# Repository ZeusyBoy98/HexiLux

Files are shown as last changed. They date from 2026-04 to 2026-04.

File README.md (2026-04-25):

# HexiLux
Made for Hack Club Fallout.

## Zine
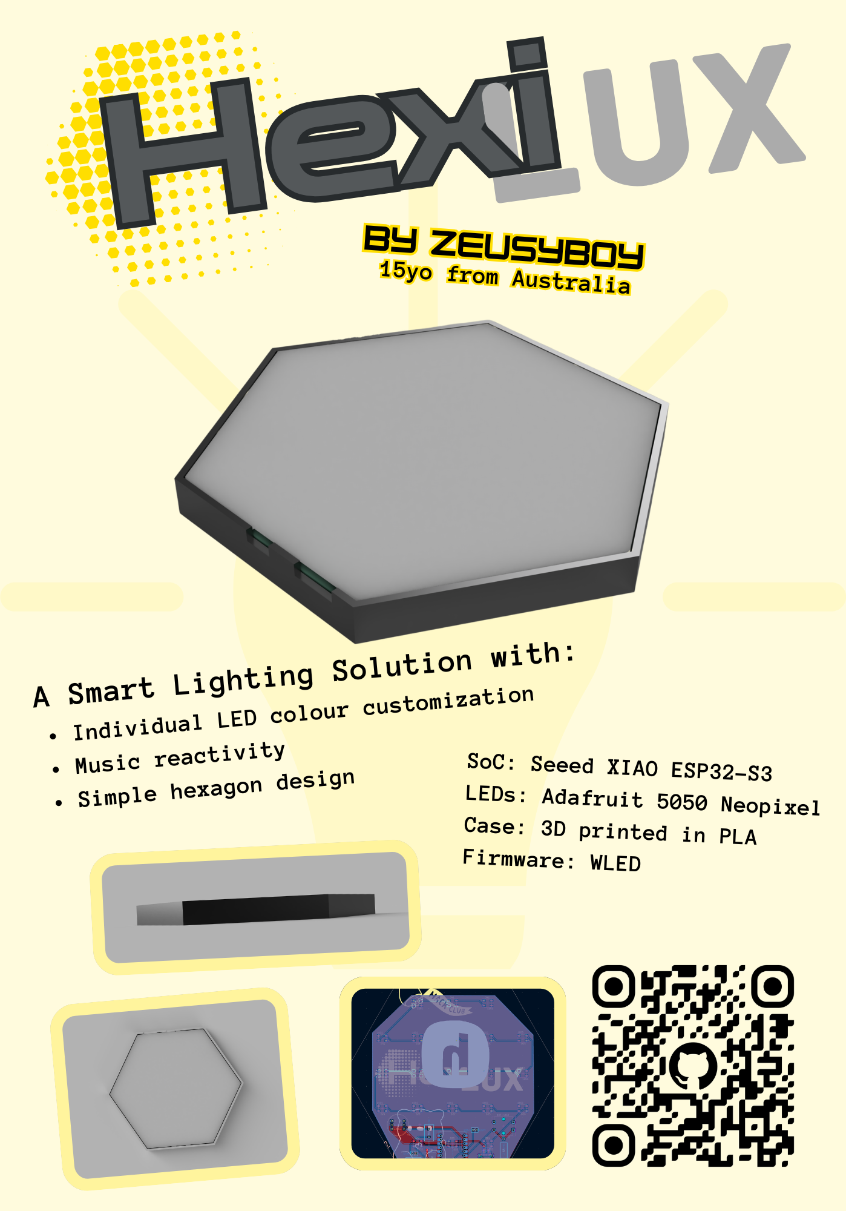
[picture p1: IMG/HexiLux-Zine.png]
Zine


## What does it do?
A custom open-source smart lighting solution, using tiling hexagonal panels. Featuring music sync and home assistant compatibility. 

## Why/Motivation?
Because I enjoy DJing and music reactive lights to go behind my setup would be really cool and elevate my experience.

## How?
In order to make this project for yourself, you'll need to purchase/3D print the items in the bill of materials below.

| Quantity | Item | URL | Unit Price ($USD) | Total Price ($USD)  |
| --- | --- | --- | --- | --- |
| 1 | Microphone | [Zaitronics](https://zaitronics.com.au/products/inmp441-i2s-mems-omnidirectional-microphone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) | 5.57 | 5.57 |
| 3 | Neopixel (10 pack) | [DigiKey](https://www.digikey.com.au/en/products/detail/adafruit-industries-llc/1655/5154679) | 4.50 | 13.50 |
| 1 | Button | [DigiKey](https://www.digikey.com.au/en/products/detail/omron-electronics-inc-emc-div/B3F-4050/95200) | 0.52 | 0.52 |
| 1 | Board<br> | [DigiKey](https://www.digikey.com.au/en/products/detail/seeed-technology-co-ltd/113991114/19285530) | 7.49 | 7.49 |
| 4 | 100nF Capacitor | [DigiKey](https://www.digikey.com.au/en/products/detail/vishay-beyschlag-draloric-bc-components/K104K15X7RF5TL2/286538) | 0.28 | 1.12 |
| 1 | 330 Resistor | [DigiKey](https://www.digikey.com.au/en/products/detail/yageo/FMP200JR-52-330R/2058682) | 0.19 | 0.19 |
| 1 | 10k Resistor | [DigiKey](https://www.digikey.com.au/en/products/detail/yageo/FMP200JR-52-10K/2058646) | 0.19 | 0.19 |
| 2 | 5.1k Resistor | [DigiKey](https://www.digikey.com.au/en/products/detail/yageo/RC0603FR-075K1L/727268) | 0.10 | 0.20 |
| 1 | 47uF Capacitor | [DigiKey](https://www.digikey.com.au/en/products/detail/tdk/FK20X5R0J476MN000/2815373) | 0.86 | 0.86 |
| 1 | 100uF Capacitor | [DigiKey](https://www.digikey.com.au/en/products/detail/murata-electronics/GRM31CD80J107MEA8L/13904781) | 0.44 | 0.44 |
| 1 | Level Shifter | [DigiKey](https://www.digikey.com.au/en/products/detail/texas-instruments/SN74AHCT1G125DBVR/376028) | 0.14 | 0.14 |
| 1 | USBC | [DigiKey](https://www.digikey.com.au/en/products/detail/amphenol-cs-fci/10155435-00011LF/11602060) | 0.85 | 0.85 |
| | Case | 3D print files in /CAD | (3D printing: 1.17) | (3D printing: 1.17) |
| PCB | | | | 29.24 |
| Shipping | | | | 3.70+20+9.52=33.22  |
| Total | | | | 93.53 |

### Build Guide:

#### 1. Preparation
Before starting, make sure you have:
<ul>
<li>All components from the BOM
<li>A soldering iron + solder
<li>Tweezers (there are lots of small components)
<li>Flux (helpful)
<li>A 3D printer (or get the printed parts from someone else)
<li>A USB-C cable
<li>A USB-C power adapter
</ul>

#### 2. Soldering
Take your pcb and begin soldering components to it<br>
Wiring schematic:
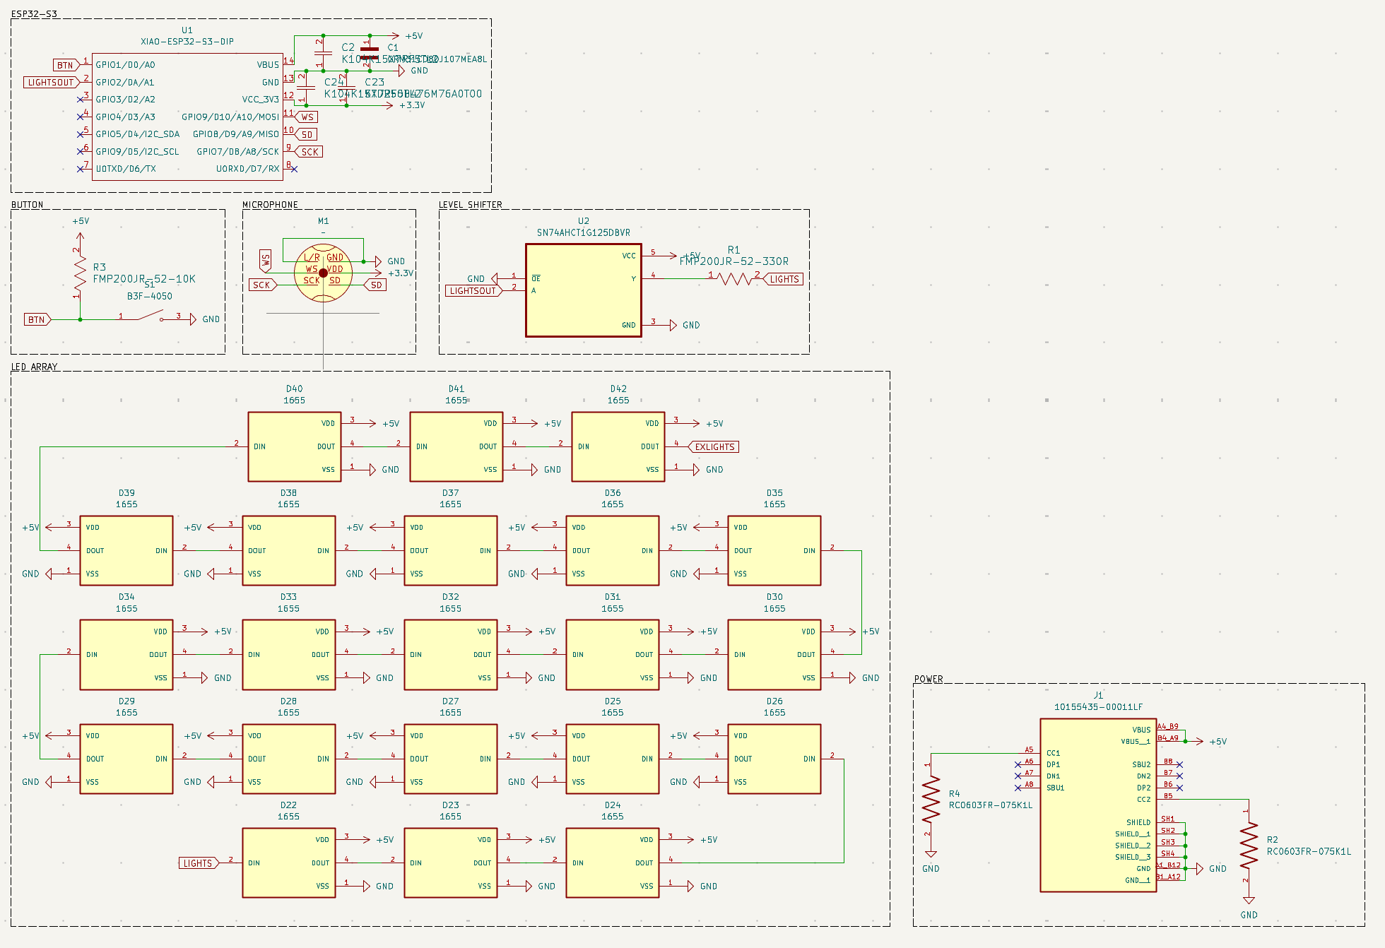
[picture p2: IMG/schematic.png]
schematic

Recommended order:
<ul>
<li>SMD Components (resistors/capacitors, neopixels, logic converters)
<li>Microcontroller (Seeed XIAO ESP32-S3)
<li>Through-hole components (resistors/capacitors, buttons, microphone)
</ul>

#### 3. Case
<ul>
<li>3D print the case bottom and top.
<li>Place the PCB into the case bottom
<li>Snap on the case top
</ul>

#### 4. Firmware
<ul>
<li>Plug the middle USB-C port (ESP32-S3) into a computer
<li>Go to https://install.wled.me/
<li>Install the WLED firmware to the board
<li>Unplug
<li>Plug a power adapter into the off-centre USB-C port
<li>Follow the instructions here to start using: https://kno.wled.ge/basics/getting-started/
</ul>

Enjoy your HexiLux panel!

## Renders
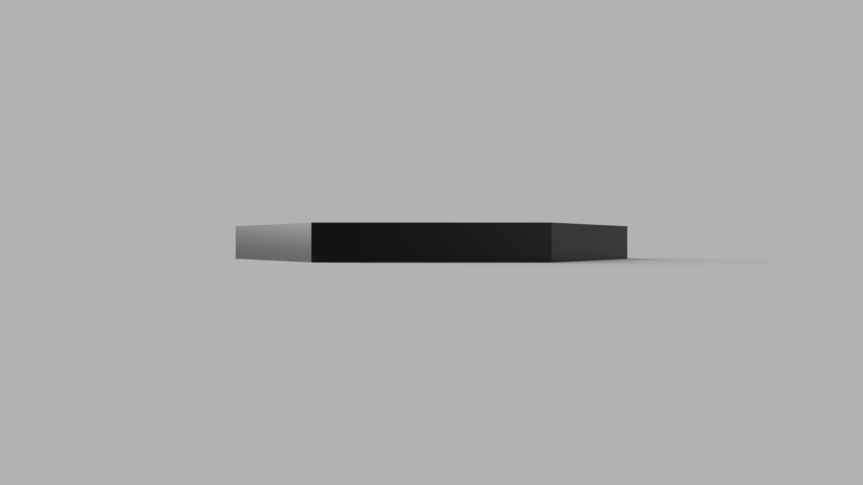
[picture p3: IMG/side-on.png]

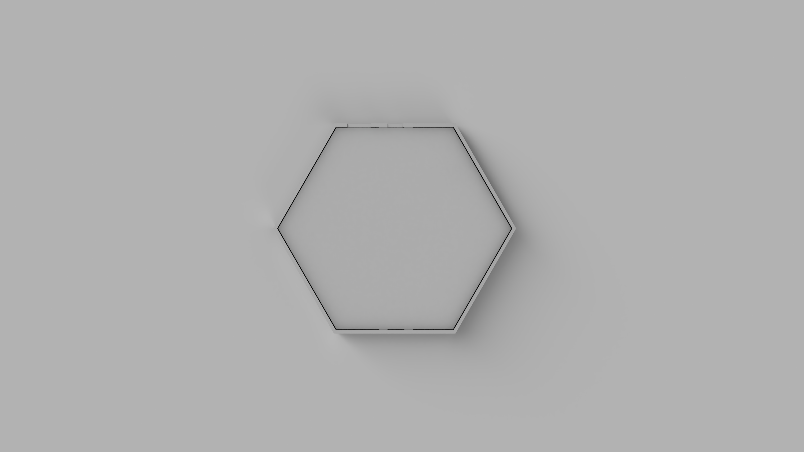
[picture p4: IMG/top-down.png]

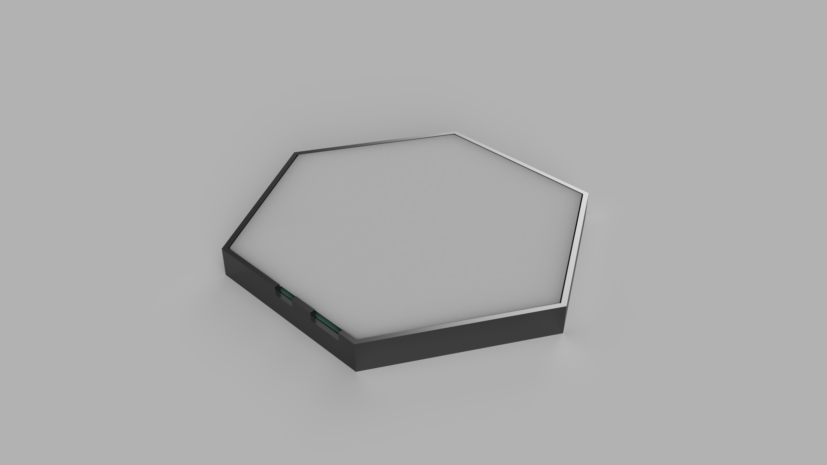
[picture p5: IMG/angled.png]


## Designing
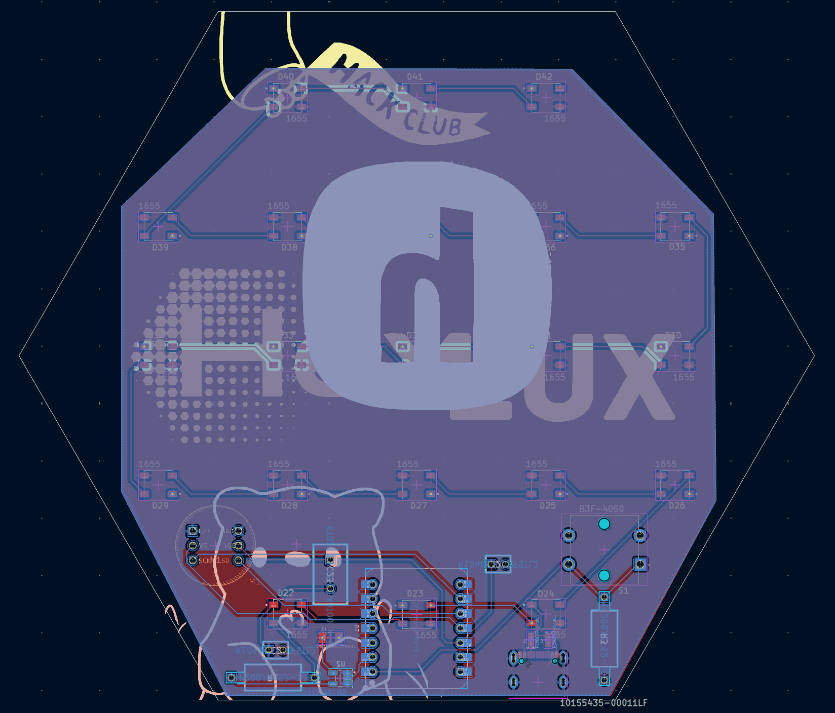
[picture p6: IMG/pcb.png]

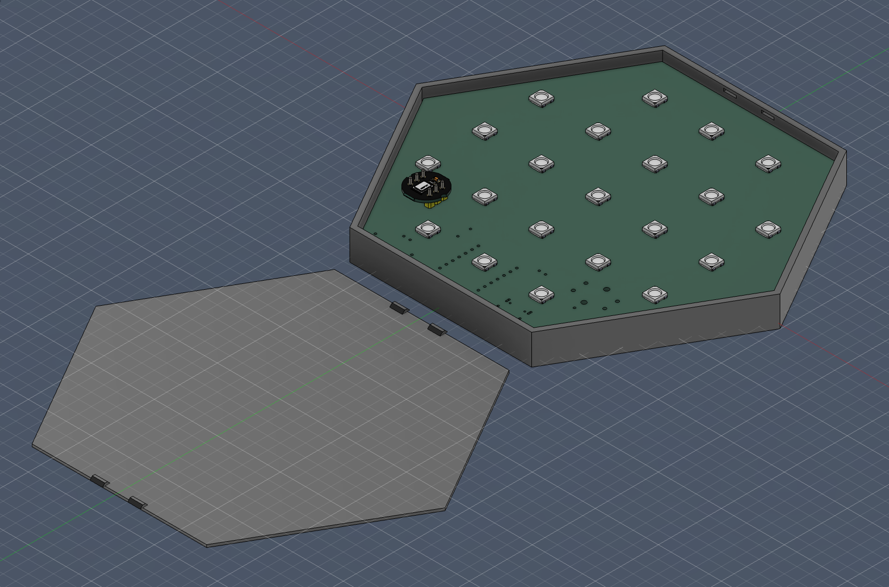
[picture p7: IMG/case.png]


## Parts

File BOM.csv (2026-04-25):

Quantity | Item | URL | Unit Price ($USD) | Total Price ($USD)
1 | Microphone | https://zaitronics.com.au/products/inmp441-i2s-mems-omnidirectional-microphone?variant=51395922100516 | 5.57 | 5.57
3 | Neopixel (10 pack) | https://www.digikey.com.au/en/products/detail/adafruit-industries-llc/1655/5154679 | 4.50 | 13.50
1 | Button | https://www.digikey.com.au/en/products/detail/omron-electronics-inc-emc-div/B3F-4050/95200 | 0.52 | 0.52
1 | Board<br> | https://www.digikey.com.au/en/products/detail/seeed-technology-co-ltd/113991114/19285530 | 7.49 | 7.49
4 | 100nF Capacitor | https://www.digikey.com.au/en/products/detail/vishay-beyschlag-draloric-bc-components/K104K15X7RF5TL2/286538 | 0.28 | 1.12
1 | 330 Resistor | https://www.digikey.com.au/en/products/detail/yageo/FMP200JR-52-330R/2058682 | 0.19 | 0.19
1 | 10k Resistor | https://www.digikey.com.au/en/products/detail/yageo/FMP200JR-52-10K/2058646 | 0.19 | 0.19
2 | 5.1k Resistor | https://www.digikey.com.au/en/products/detail/yageo/RC0603FR-075K1L/727268 | 0.10 | 0.20
1 | 47uF Capacitor | https://www.digikey.com.au/en/products/detail/tdk/FK20X5R0J476MN000/2815373 | 0.86 | 0.86
1 | 100uF Capacitor | https://www.digikey.com.au/en/products/detail/murata-electronics/GRM31CD80J107MEA8L/13904781 | 0.44 | 0.44
1 | Level Shifter | https://www.digikey.com.au/en/products/detail/texas-instruments/SN74AHCT1G125DBVR/376028 | 0.14 | 0.14
1 | USBC | https://www.digikey.com.au/en/products/detail/amphenol-cs-fci/10155435-00011LF/11602060 | 0.85 | 0.85
 | Case | 3D print files in /CAD | (3D printing: 1.17) | (3D printing: 1.17)
PCB |  |  |  | 29.24
Shipping |  |  |  | 3.70+20+9.52=33.22
Total |  |  |  | 93.53

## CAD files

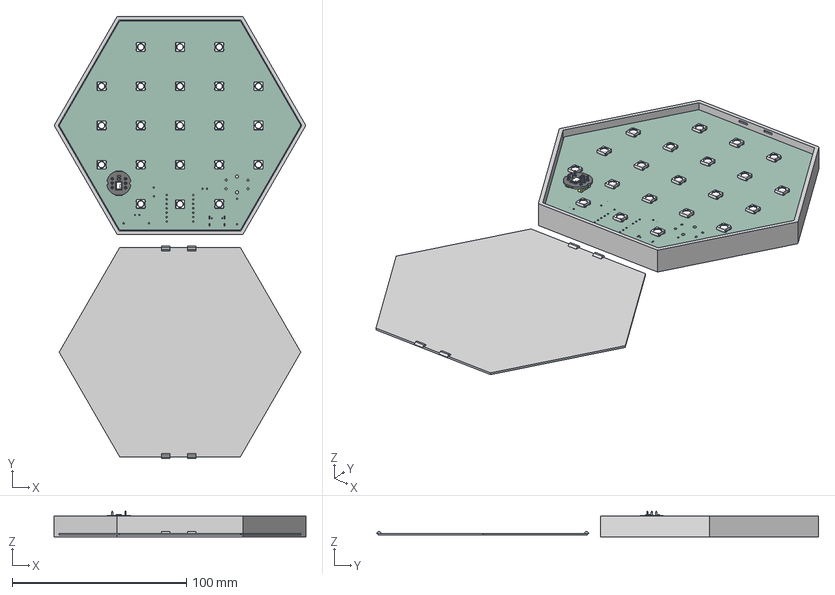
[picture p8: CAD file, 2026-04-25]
CAD/HexiLux-Full.stp
144.4 x 253.5 x 14.7 mm

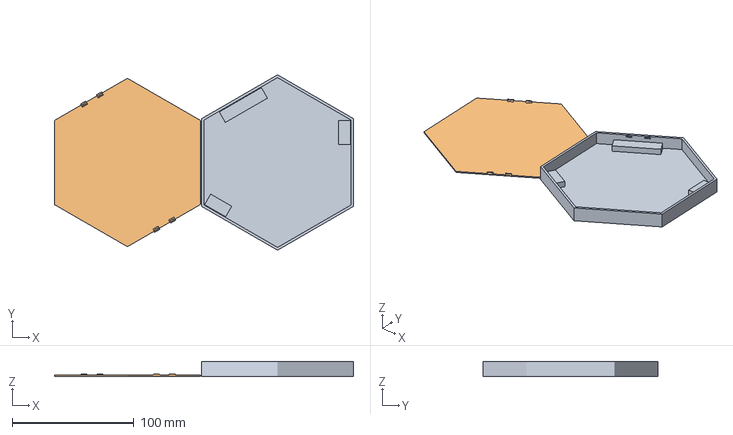
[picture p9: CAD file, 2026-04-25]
CAD/HexiLux-Print.3mf
246.0 x 144.3 x 12.0 mm
HexiLux-Bottom.stp
HexiLux-Top.stp

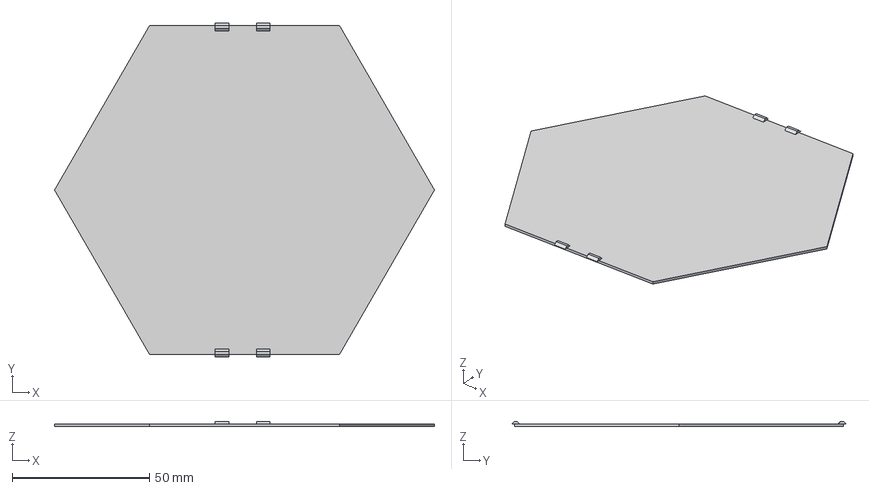
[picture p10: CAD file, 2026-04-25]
CAD/Parts/HexiLux-Top.stp
138.6 x 122.0 x 2.00 mm

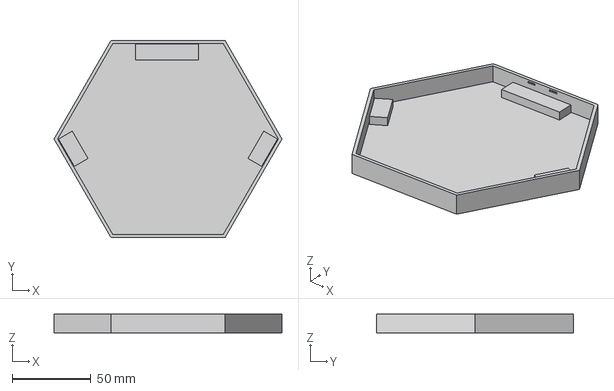
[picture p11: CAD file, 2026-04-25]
CAD/Parts/HexiLux-Bottom.stp
144.4 x 125.0 x 12.0 mm

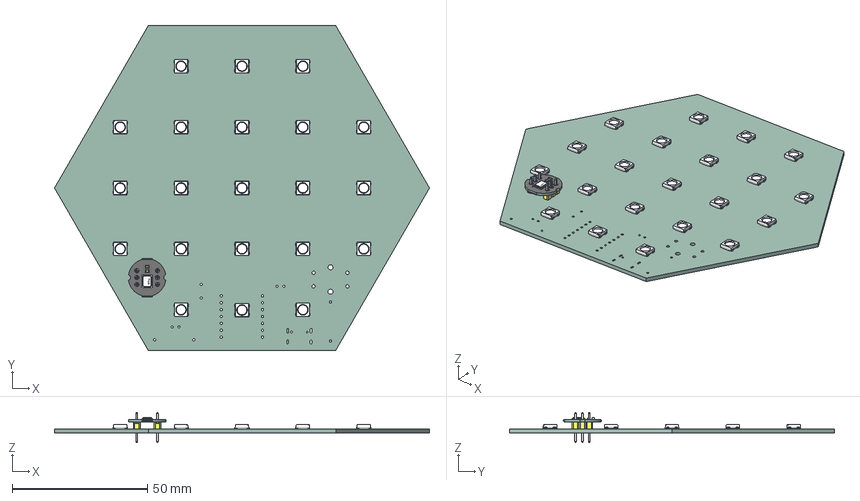
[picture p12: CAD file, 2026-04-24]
CAD/HexiLux-PCB.step
138.6 x 120.0 x 11.2 mm
1655_5050_neopixel x 21
0603 Resistor v1
HexiLux-v1_PCB

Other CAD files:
CAD/HexiLux-Full.f3d

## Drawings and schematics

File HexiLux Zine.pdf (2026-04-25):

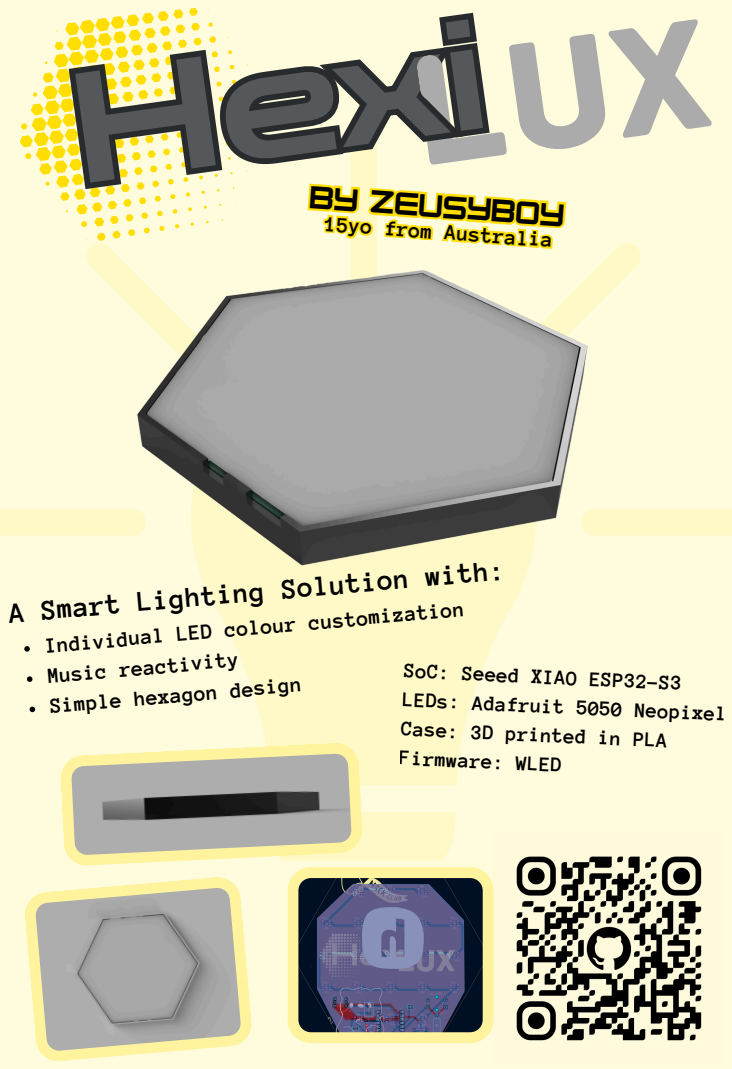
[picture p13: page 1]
HexLiux; 15yo from Australia 1; usyBoy; Firmware: WLED

By ZeusyBoy By ZeusyBoy B

om Australia 15yo from Australia

A Smart Lighting Solution with:

Individual LED colour customization Music reactivity Simple hexagon design

SoC: Seeed XIAO ESP32-S3

LEDs: Adafruit 5050 Neopixel

Case: 3D printed in PLA

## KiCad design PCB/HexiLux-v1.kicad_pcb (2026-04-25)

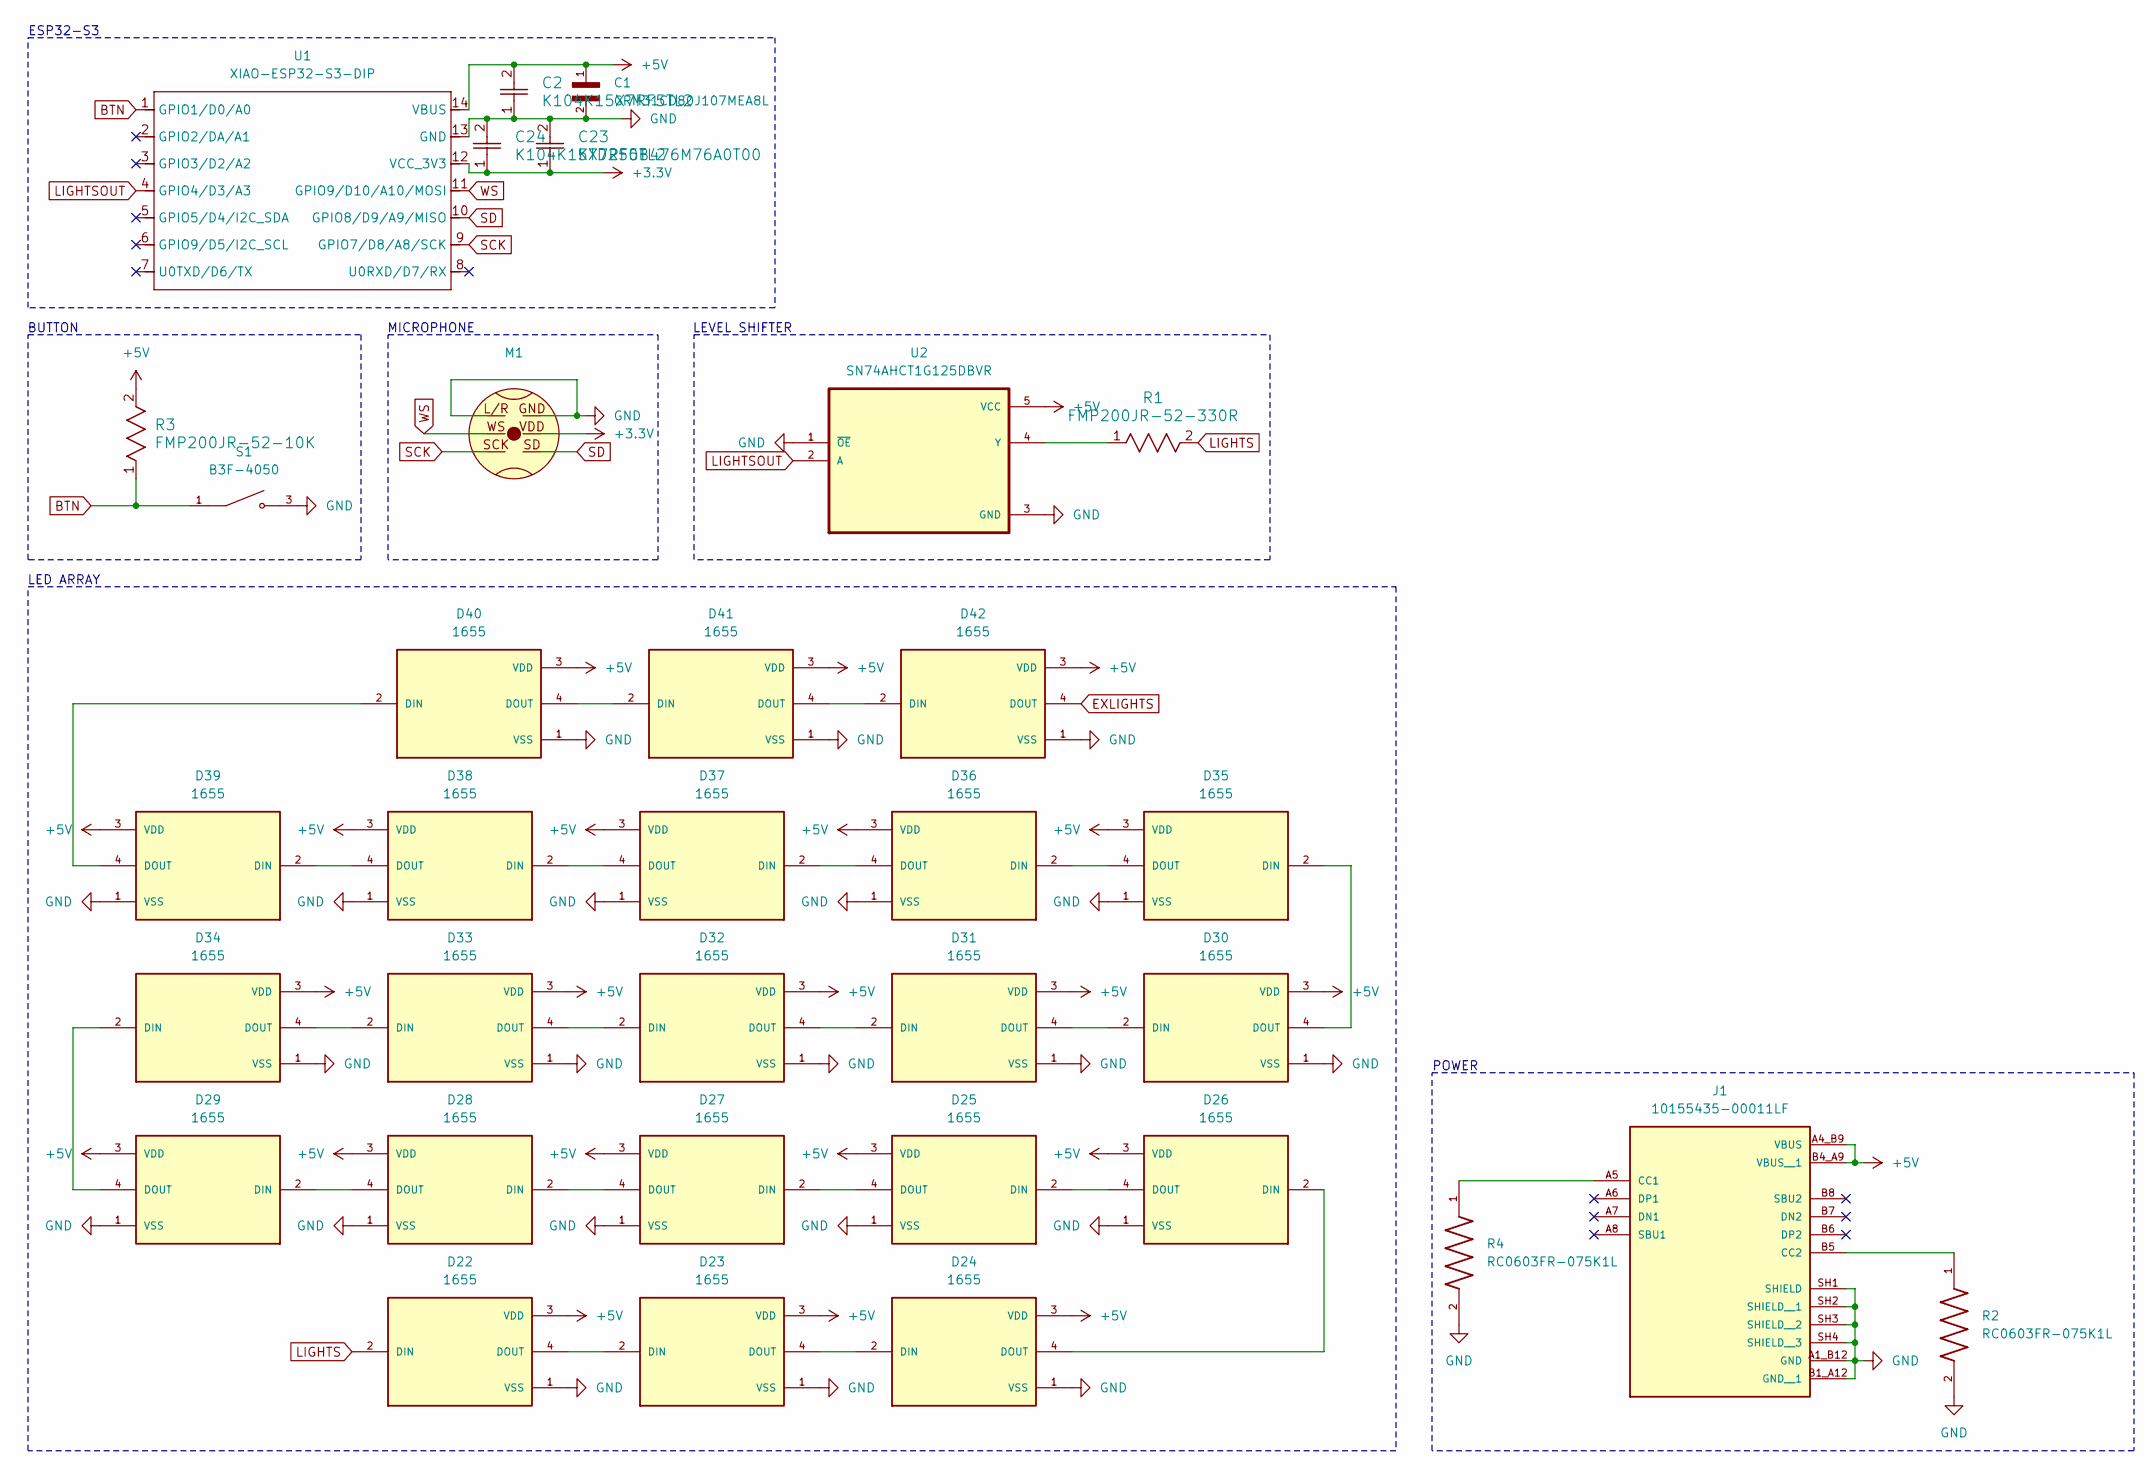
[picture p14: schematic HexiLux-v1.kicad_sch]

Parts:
C1: GRM31CD80J107MEA8L; 100uf_5V_1206; DigiKey_Part_Number 490-GRM31CD80J107MEA8LCT-ND
C2, C24: K104K15X7RF5TL2; K104K15X7RF5TL2_VIS
C23: KTD250B476M76A0T00; CAP_NTD_76_05.5T_NIP
D22, D23, D24, D25, D26, D27, D28, D29, D30, D31, D32, D33, D34, D35, D36, D37, D38, D39, D40, D41, D42: 1655; LED_1655_5050_neopixel; PARTREV 01
J1: 10155435-00011LF; AMPHENOL_10155435-00011LF; PARTREV C
M1: INMP441
R1: FMP200JR-52-330R; YAG_FMP200_YAG_52_330k
R2, R4: RC0603FR-075K1L; 5.1k_0603_DK
R3: FMP200JR-52-10K; YAG_FMP200_YAG
S1: B3F-4050; SW_B3F-4050; DigiKey_Part_Number SW413-ND
U1: XIAO-ESP32-S3-DIP
U2: SN74AHCT1G125DBVR; 74AHCT_level_shifter

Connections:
+3.3V: C23.1, C24.1, M1.VDD, U1.12 (VCC_3V3)
+5V: C1.1, C2.2, D22.3 (VDD), D23.3 (VDD), D24.3 (VDD), D25.3 (VDD), D26.3 (VDD), D27.3 (VDD), D28.3 (VDD), D29.3 (VDD), D30.3 (VDD), D31.3 (VDD), D32.3 (VDD), D33.3 (VDD), D34.3 (VDD), D35.3 (VDD), D36.3 (VDD), D37.3 (VDD), D38.3 (VDD), D39.3 (VDD), D40.3 (VDD), D41.3 (VDD), D42.3 (VDD), J1.A4_B9 (VBUS), J1.B4_A9 (VBUS__1), R3.2, U1.14 (VBUS), U2.5 (VCC)
BTN: R3.1, S1.1, S1.2, U1.1 (GPIO1/D0/A0)
EXLIGHTS: D42.4 (DOUT)
GND: C1.2, C2.1, C23.2, C24.2, D22.1 (VSS), D23.1 (VSS), D24.1 (VSS), D25.1 (VSS), D26.1 (VSS), D27.1 (VSS), D28.1 (VSS), D29.1 (VSS), D30.1 (VSS), D31.1 (VSS), D32.1 (VSS), D33.1 (VSS), D34.1 (VSS), D35.1 (VSS), D36.1 (VSS), D37.1 (VSS), D38.1 (VSS), D39.1 (VSS), D40.1 (VSS), D41.1 (VSS), D42.1 (VSS), J1.A1_B12 (GND), J1.B1_A12 (GND__1), J1.SH1 (SHIELD), J1.SH2 (SHIELD__1), J1.SH3 (SHIELD__2), J1.SH4 (SHIELD__3), M1.GND, M1.L/R, R2.2, R4.2, S1.3, S1.4, U1.13 (GND), U2.1 (~OE), U2.3 (GND)
LIGHTS: D22.2 (DIN), R1.2
LIGHTSOUT: U1.4 (GPIO4/D3/A3), U2.2 (A)
unnamed: D22.4 (DOUT), D23.2 (DIN)
unnamed: D23.4 (DOUT), D24.2 (DIN)
unnamed: D24.4 (DOUT), D26.2 (DIN)
unnamed: D25.2 (DIN), D26.4 (DOUT)
unnamed: D25.4 (DOUT), D27.2 (DIN)
unnamed: D27.4 (DOUT), D28.2 (DIN)
unnamed: D28.4 (DOUT), D29.2 (DIN)
unnamed: D29.4 (DOUT), D34.2 (DIN)
unnamed: D30.2 (DIN), D31.4 (DOUT)
unnamed: D30.4 (DOUT), D35.2 (DIN)
unnamed: D31.2 (DIN), D32.4 (DOUT)
unnamed: D32.2 (DIN), D33.4 (DOUT)
unnamed: D33.2 (DIN), D34.4 (DOUT)
unnamed: D35.4 (DOUT), D36.2 (DIN)
unnamed: D36.4 (DOUT), D37.2 (DIN)
unnamed: D37.4 (DOUT), D38.2 (DIN)
unnamed: D38.4 (DOUT), D39.2 (DIN)
unnamed: D39.4 (DOUT), D40.2 (DIN)
unnamed: D40.4 (DOUT), D41.2 (DIN)
unnamed: D41.4 (DOUT), D42.2 (DIN)
unnamed: J1.A5 (CC1), R4.1
unnamed: J1.B5 (CC2), R2.1
unnamed: R1.1, U2.4 (Y)
SCK: M1.SCK, U1.9 (GPIO7/D8/A8/SCK)
SD: M1.SD, U1.10 (GPIO8/D9/A9/MISO)
WS: M1.WS, U1.11 (GPIO9/D10/A10/MOSI)

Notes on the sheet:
POWER
LED ARRAY
BUTTON
MICROPHONE
ESP32-S3
LEVEL SHIFTER

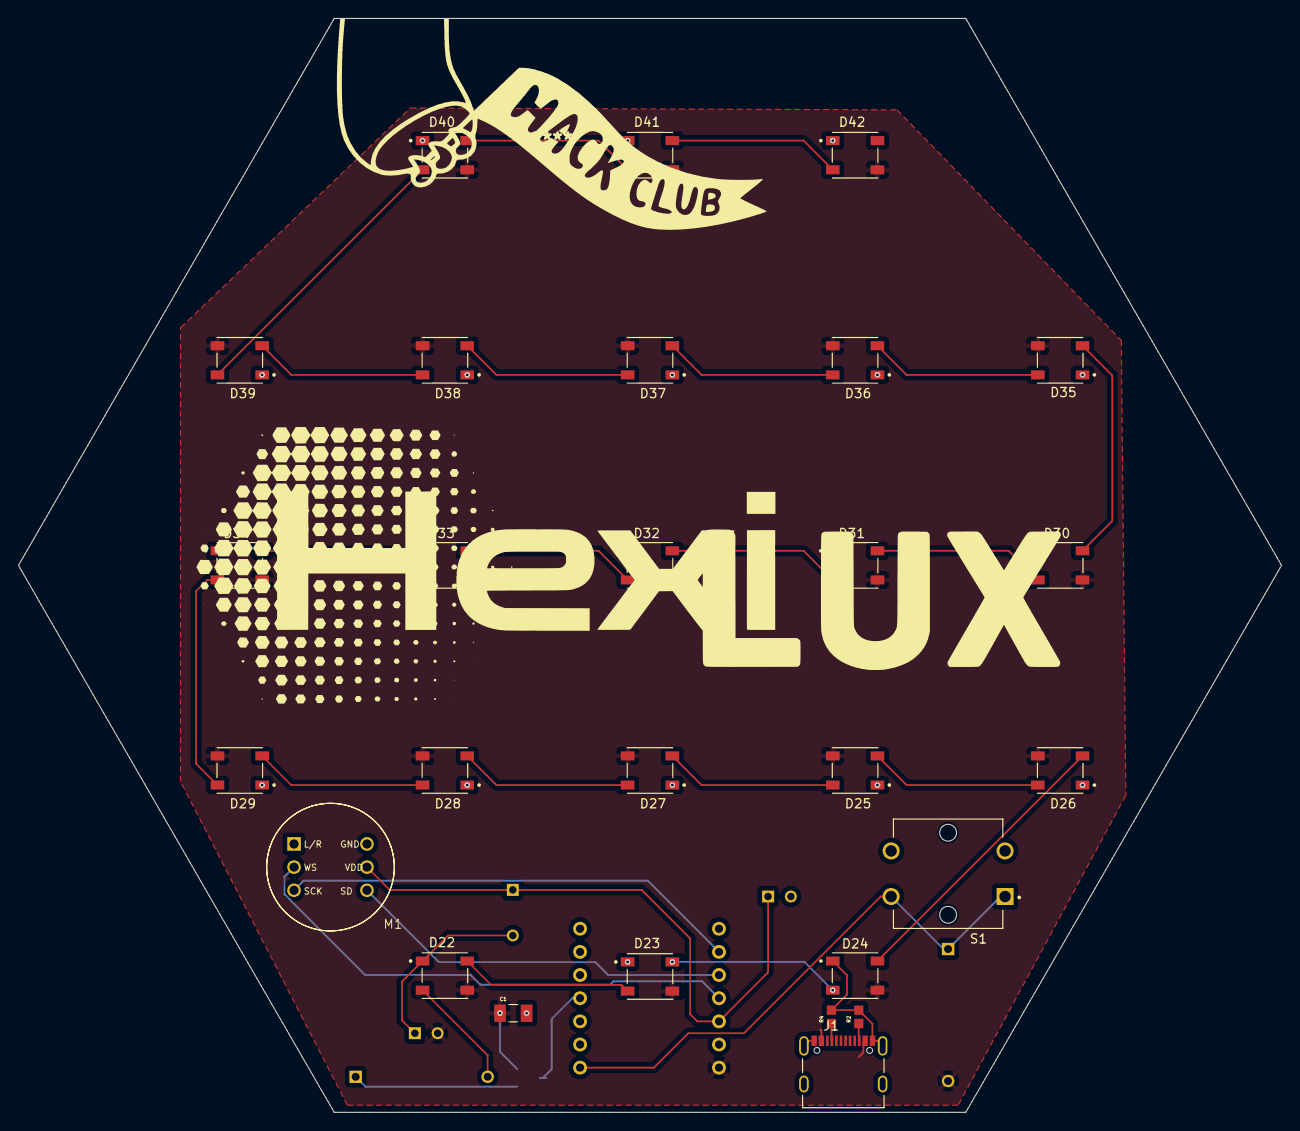
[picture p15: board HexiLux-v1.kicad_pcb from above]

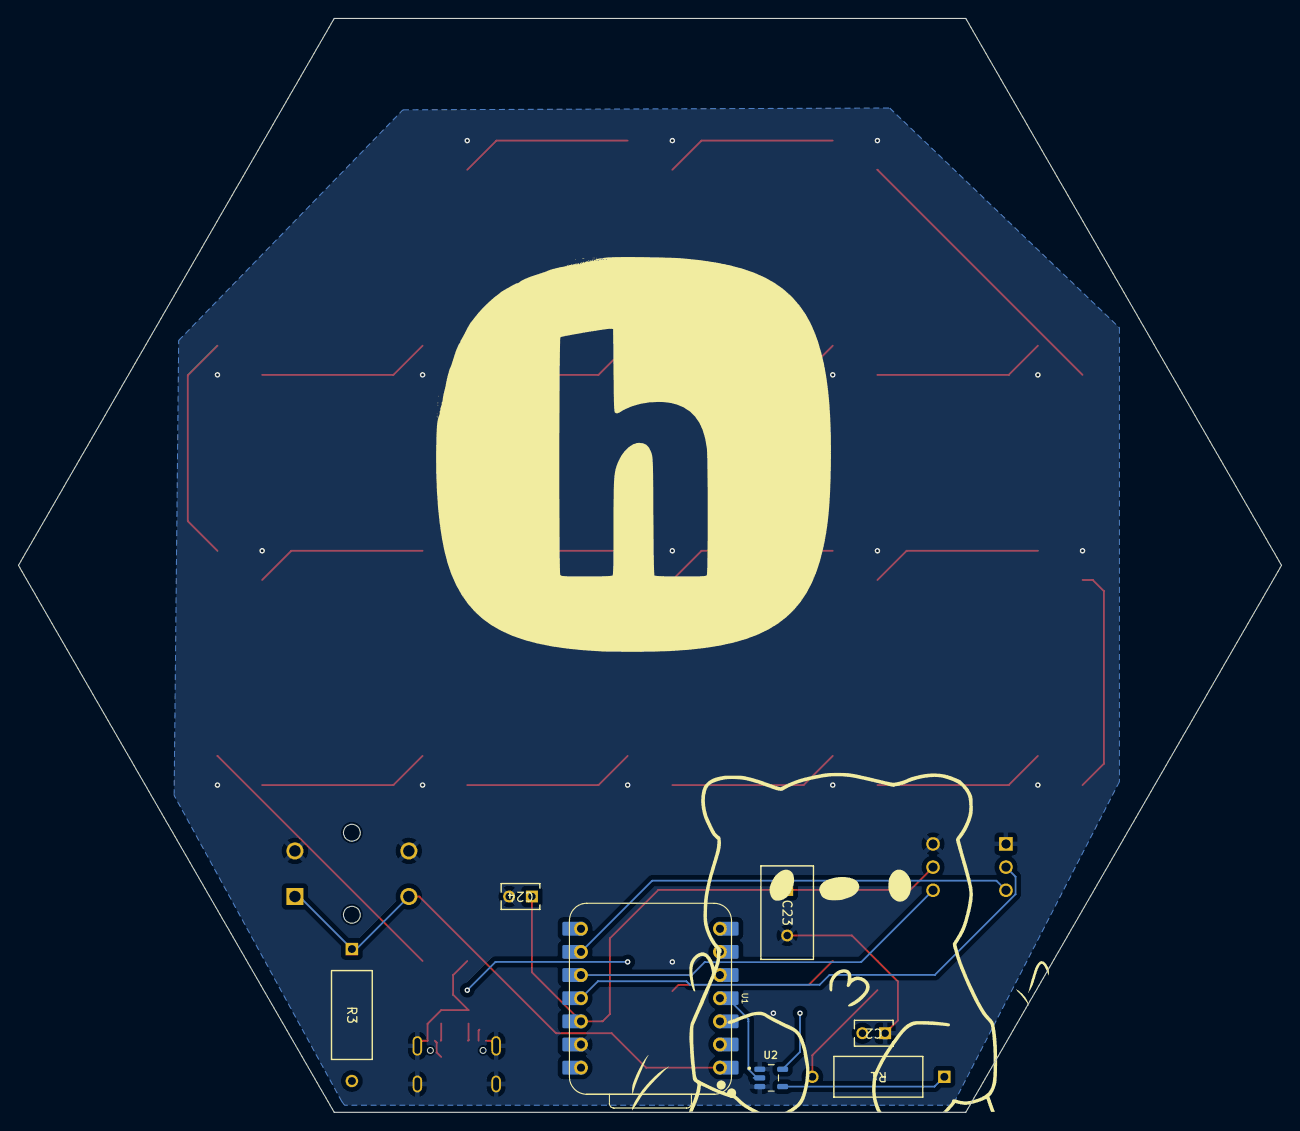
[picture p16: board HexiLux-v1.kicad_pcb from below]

Board: 2 copper layers, 138.6 x 120.0 mm, 34 parts (7 on the bottom side), 32 nets.

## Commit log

2026-03-21 Add PCB files
    [HexiLux-v1.kicad_pcb, HexiLux-v1.kicad_sch]
2026-04-24 Start work on CAD
    [HexiLux-PCB.step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]
2026-04-25 Export CAD files & finish BOM
    [BOM.csv, HexiLux-Bottom.stp, HexiLux-Full.f3d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]
2026-04-25 Fixing gerbers
    [HexiLux-v1-B_Cu.gbr, HexiLux-v1-B_Mask.gbr, HexiLux-v1-B_Paste.gbr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]
2026-04-25 Readd gerbers
    [HexiLux-v1-B_Cu.gbr, HexiLux-v1-B_Mask.gbr, HexiLux-v1-B_Paste.gbr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]
2026-04-25 Add wiring schematic to build guide
